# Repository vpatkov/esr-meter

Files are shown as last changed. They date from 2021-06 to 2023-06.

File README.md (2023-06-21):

# ESR meter

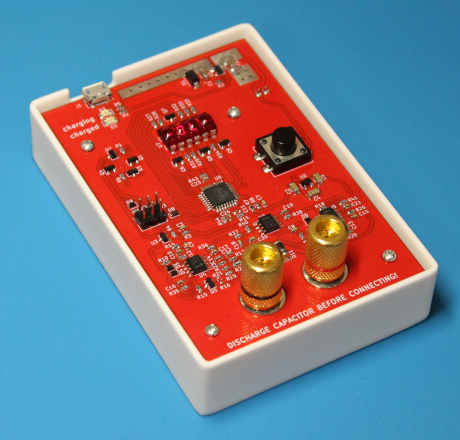
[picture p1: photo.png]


Yet another ESR meter. More precisely, it measures the impedance at 100 kHz in
assumption it's pure resistive. So this meter is not for laboratory
measurements, but for finding bad electrolytic capacitors (a typical fault in
aged electronics).

- The test signal is 100 kHz 50 mVpp 10 Ω sine wave
- Rechargeable from Micro-USB at 300 mA (Li-Po/Li-ion)
- Auto power-off after 3 minutes of inactivity

## Usage

To switch the meter on or off, press the button.

On startup, the meter performs a self-test. Keep the terminals open. During the
test, the meter turns on all the segments on the display, then shows an error
if any. Errors are:

- `E.F.LO`: low fuel (battery voltage < 3.3 V);
- `E.rEF`: something wrong with voltage references or ADC;
- `E.Prb`: something wrong with the test signal (or the terminals aren't open).

When the test is passed, the meter shows the current battery level in percents
as `F <level>`.

During normal operation the meter continuously shows the measured ESR in Ω,
or `-OL-` if it's more than 99.99 Ω.

To compensate test leads (set zero), short the leads and long press the button.
You can't compensate more than 2 Ω — find a better leads or connect capacitors
directly to the binding post. Note that inductance of wires matters at 100 kHz.
If the meter refuse to compensate, it shows `SHIt` (stands for "your leads are
shit").

## License

Unless otherwise noted, this work is licensed under Creative Commons Zero 1.0.



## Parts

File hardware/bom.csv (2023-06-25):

# | Reference | Qty | Value | Footprint | DNP | Note
1 | C1, C6 | 2 | 4.7μ | Capacitor_SMD:C_1206_3216Metric
2 | C2, C4, C5 | 3 | 1μ | Capacitor_SMD:C_1206_3216Metric
3 | C3, C8, C16, C17, C18, C19, C20, C21, C22, C23, C24 | 11 | 100n | Capacitor_SMD:C_0603_1608Metric
4 | C7, C9, C10, C15 | 4 | 10n | Capacitor_SMD:C_0603_1608Metric
5 | C11 | 1 |  | Capacitor_SMD:C_0603_1608Metric | DNP
6 | C12, C14 | 2 | 1n | Capacitor_SMD:C_0603_1608Metric |  | NP0
7 | C13 | 1 | 1n | Capacitor_SMD:C_0603_1608Metric
8 | D1 | 1 | SMAJ5.0A | Diode_SMD:D_SMA
9 | D2 | 1 | RED | LED_SMD:LED_1206_3216Metric
10 | D3 | 1 | GREEN | LED_SMD:LED_1206_3216Metric
11 | D4, D5, D6, D7, D9 | 5 | BAS316 | Diode_SMD:D_SOD-323
12 | D8 | 1 | BAT54J | Diode_SMD:D_SOD-323F
13 | D10, D11 | 2 | SM4007 | Diode_SMD:D_MELF
14 | J1 | 1 | USB_B_Micro | Connector_USB:USB_Micro-B_Molex-105017-0001
15 | J2 | 1 | JST-XH | Connector_JST:JST_XH_S2B-XH-A-1_1x02_P2.50mm_Horizontal
16 | J3 | 1 | Pin Header Male | Connector_PinHeader_2.54mm:PinHeader_2x03_P2.54mm_Vertical
17 | J4 | 1 | Binding Post | esr-meter:BindingPost
18 | Q1, Q3, Q4, Q6, Q7, Q8, Q9 | 7 | DTC114E | Package_TO_SOT_SMD:SOT-23
19 | Q2 | 1 | IRLML6402 | Package_TO_SOT_SMD:SOT-23
20 | Q5 | 1 | MMBFJ113 | Package_TO_SOT_SMD:SOT-23
21 | R1, R6, R22 | 3 | 33k | Resistor_SMD:R_0603_1608Metric
22 | R2 | 1 | 3.3k | Resistor_SMD:R_0603_1608Metric
23 | R3, R4 | 2 | 3k | Resistor_SMD:R_0603_1608Metric
24 | R5, R9, R10, R18 | 4 | 10k | Resistor_SMD:R_0603_1608Metric
25 | R7 | 1 | 31.6k | Resistor_SMD:R_0603_1608Metric |  | 1%
26 | R8 | 1 | 10k | Resistor_SMD:R_0603_1608Metric |  | 1%
27 | R11 | 1 | 100 | Resistor_SMD:R_0603_1608Metric
28 | R12, R13 | 2 | 100k | Resistor_SMD:R_0603_1608Metric
29 | R14, R15, R26 | 3 | 1k | Resistor_SMD:R_0603_1608Metric
30 | R16 | 1 |  | Resistor_SMD:R_0603_1608Metric | DNP
31 | R17, R23 | 2 | 1.58k | Resistor_SMD:R_0603_1608Metric |  | 1%
32 | R19, R37 | 2 | 1k | Resistor_SMD:R_0603_1608Metric |  | 1%
33 | R20 | 1 | 3.3M | Resistor_SMD:R_0603_1608Metric
34 | R21 | 1 | 2.2k | Resistor_SMD:R_0603_1608Metric |  | 1%
35 | R24 | 1 | 499 | Resistor_SMD:R_0805_2012Metric |  | 1%
36 | R25 | 1 | 10 | Resistor_SMD:R_0805_2012Metric |  | 1%
37 | R27, R28, R29, R30, R31, R32, R33, R34 | 8 | 2.4k | Resistor_SMD:R_0603_1608Metric
38 | R35, R36, R38, R39, R41, R42, R43, R44 | 8 | 10 | Resistor_SMD:R_0603_1608Metric
39 | R40 | 1 | 45.3k | Resistor_SMD:R_0603_1608Metric |  | 1%
40 | SW1 | 1 | SW_Push | Button_Switch_THT:SW_PUSH-12mm_Wuerth-430476085716
41 | U1 | 1 | MCP73831 | Package_TO_SOT_SMD:SOT-23-5
42 | U2 | 1 | TPS60403 | Package_TO_SOT_SMD:SOT-23-5
43 | U3 | 1 | TLV431 | Package_TO_SOT_SMD:SOT-23
44 | U4, U5, U8 | 3 | OPA1678 | Package_SO:SO-8_3.9x4.9mm_P1.27mm
45 | U6 | 1 | ATmega88PA-AU | Package_QFP:TQFP-32_7x7mm_P0.8mm
46 | U7 | 1 | QDSP-6064 | Package_DIP:DIP-12_W7.62mm

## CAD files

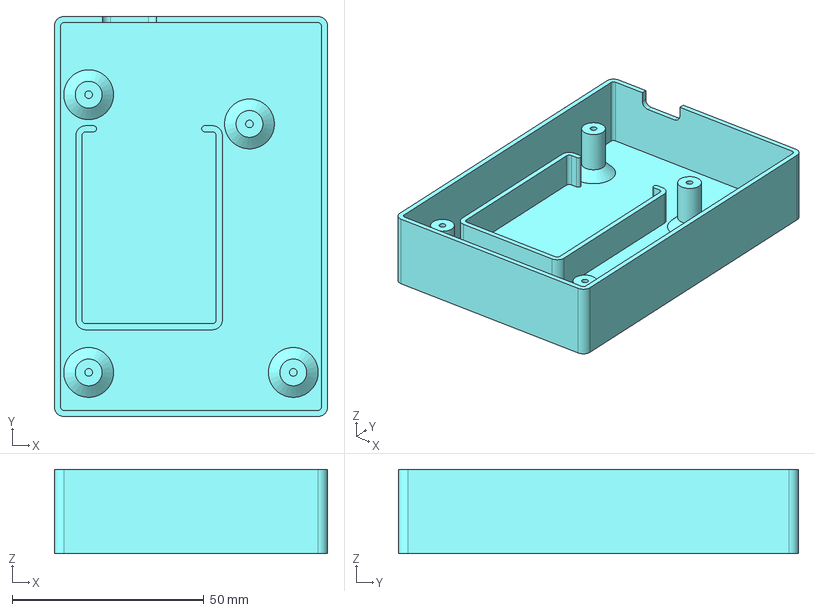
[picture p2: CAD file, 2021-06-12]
case/case.FCStd
71.2 x 104.3 x 22.0 mm

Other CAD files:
case/case.stl

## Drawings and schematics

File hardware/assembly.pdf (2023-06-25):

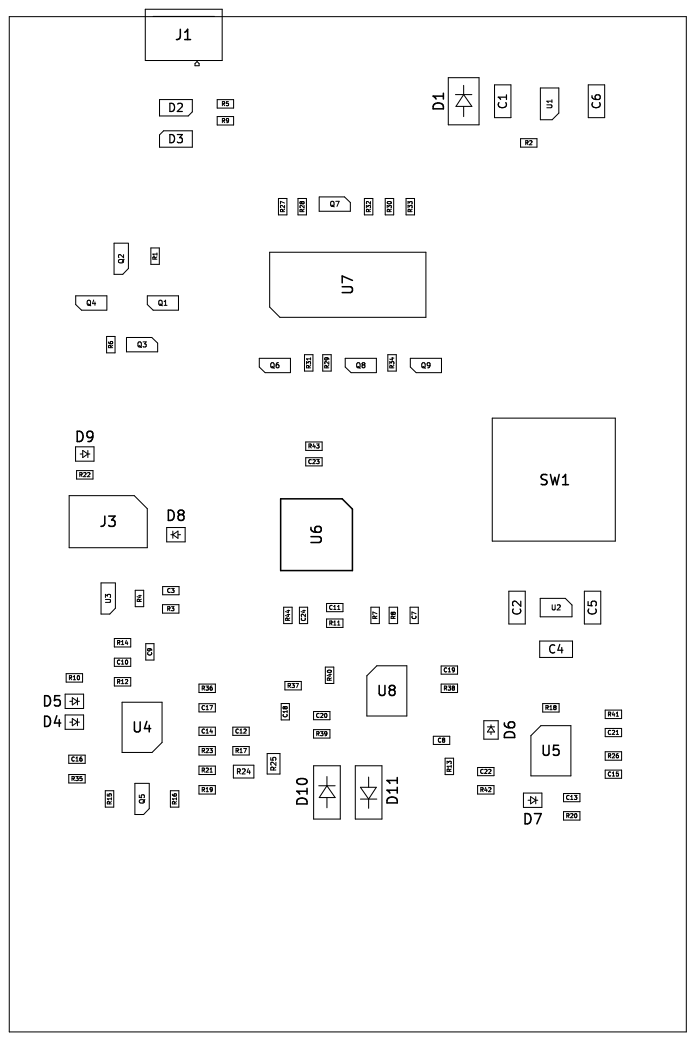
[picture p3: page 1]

Id: 1/1 Title: ESR meter File: esr-meter.kicad_pcb Sheet:

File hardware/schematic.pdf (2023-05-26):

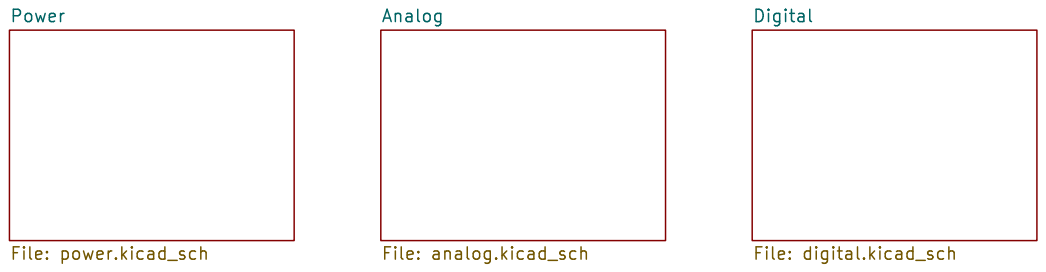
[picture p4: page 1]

Analog File: analog.kicad_sch Power File: power.kicad_sch

Id: 1/4 Title: ESR meter File: esr-meter.kicad_sch Sheet: /

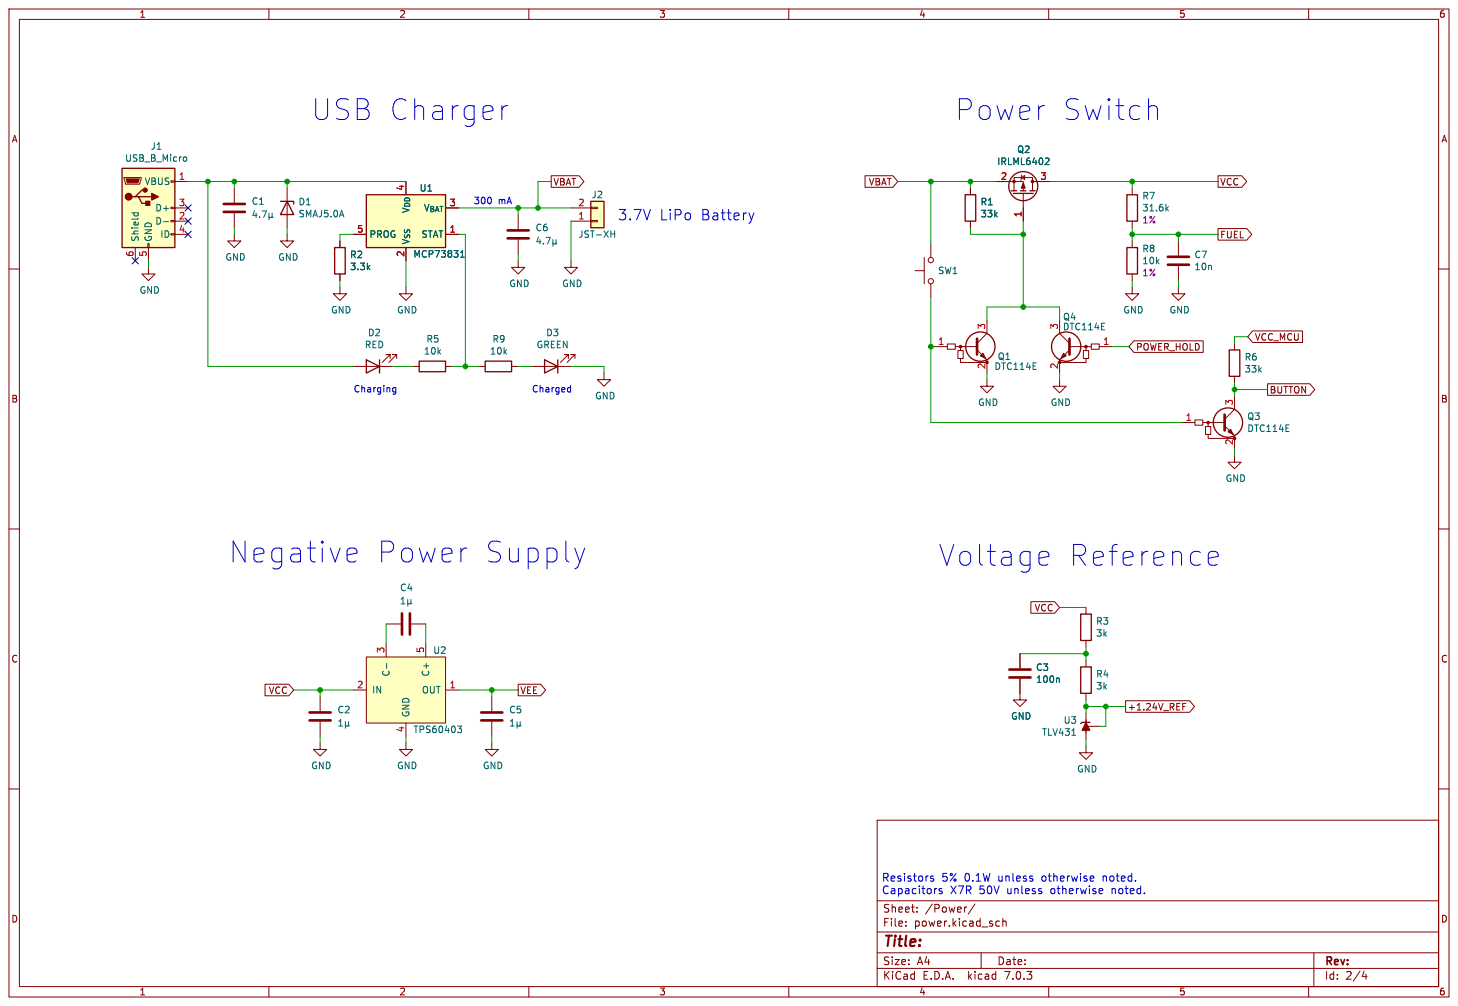
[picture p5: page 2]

Id: 2/4 Title: File: power.kicad_sch Sheet: /Power/

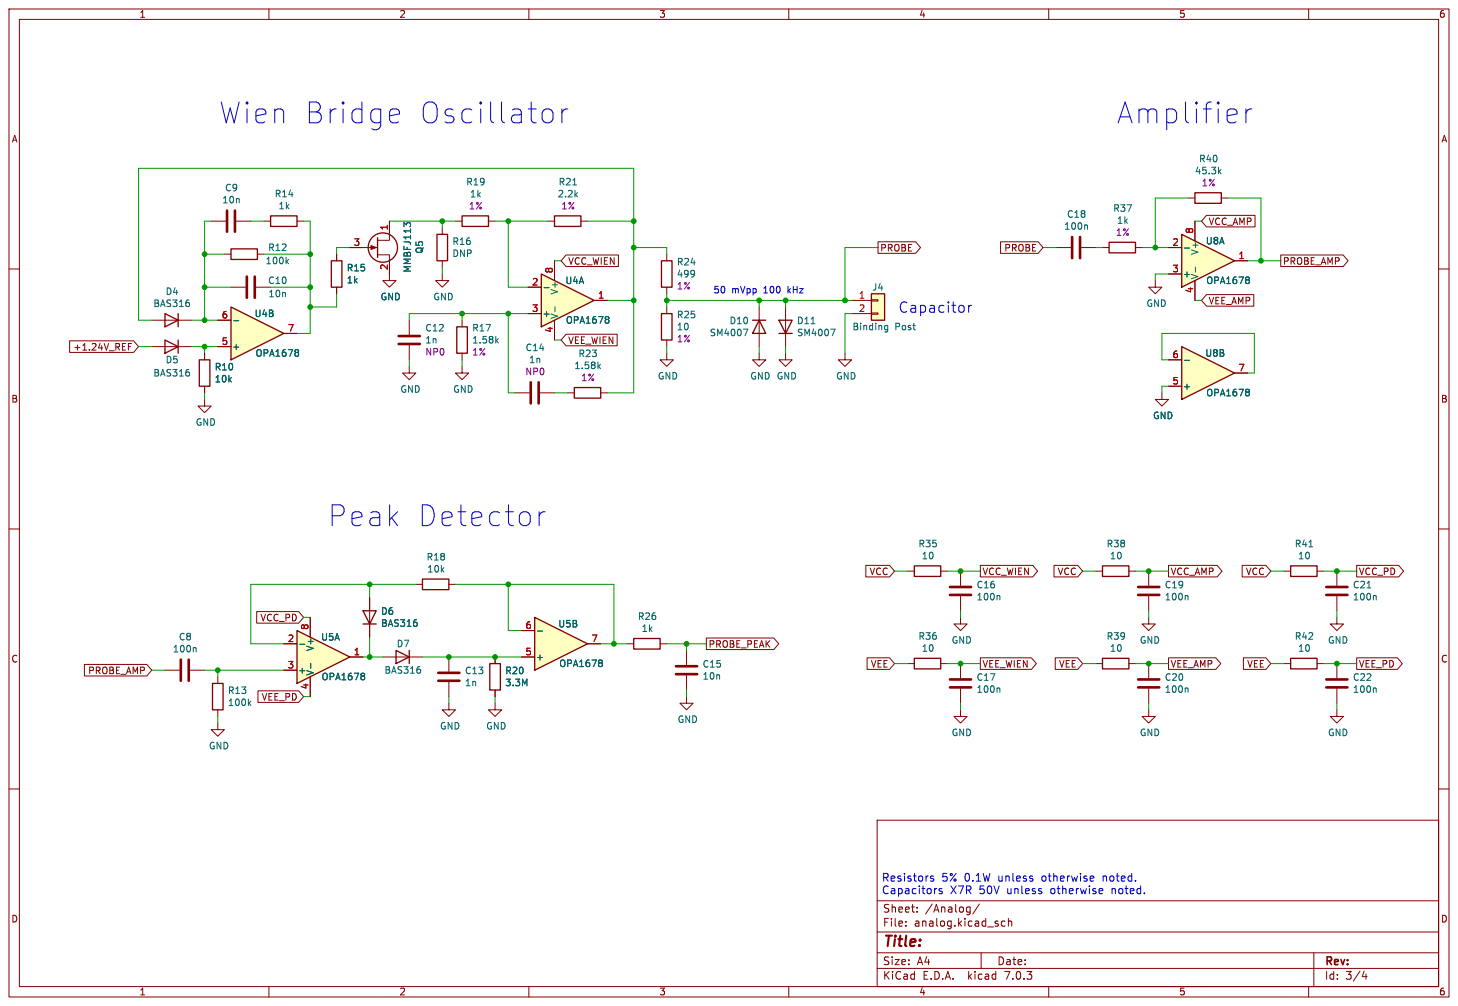
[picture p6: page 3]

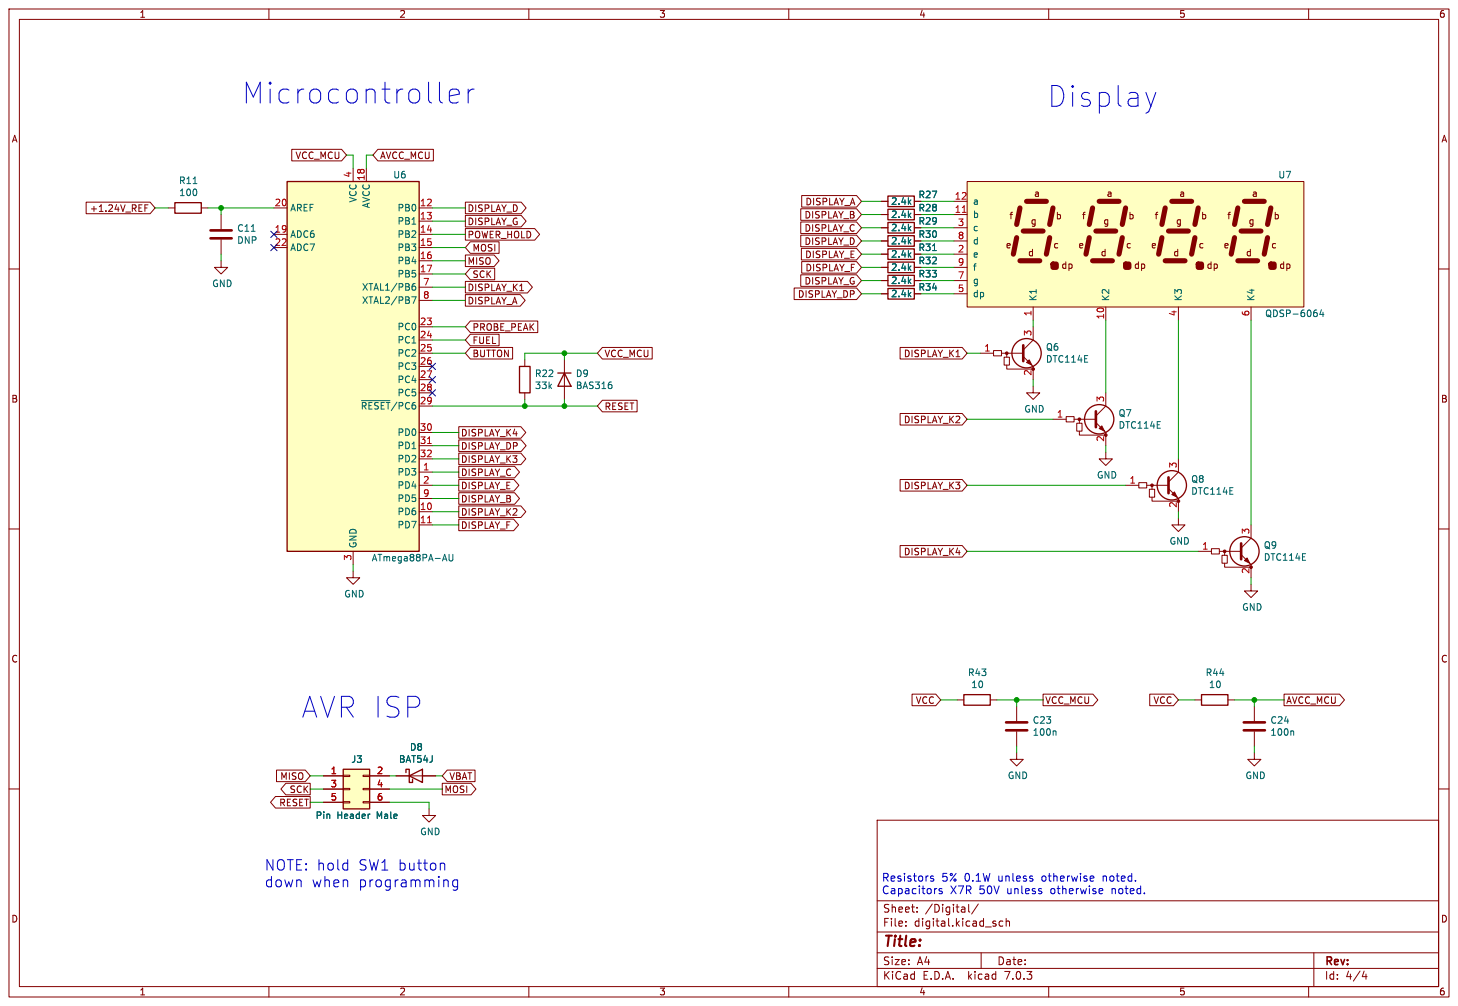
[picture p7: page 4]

Id: 4/4 Title: File: digital.kicad_sch Sheet: /Digital/

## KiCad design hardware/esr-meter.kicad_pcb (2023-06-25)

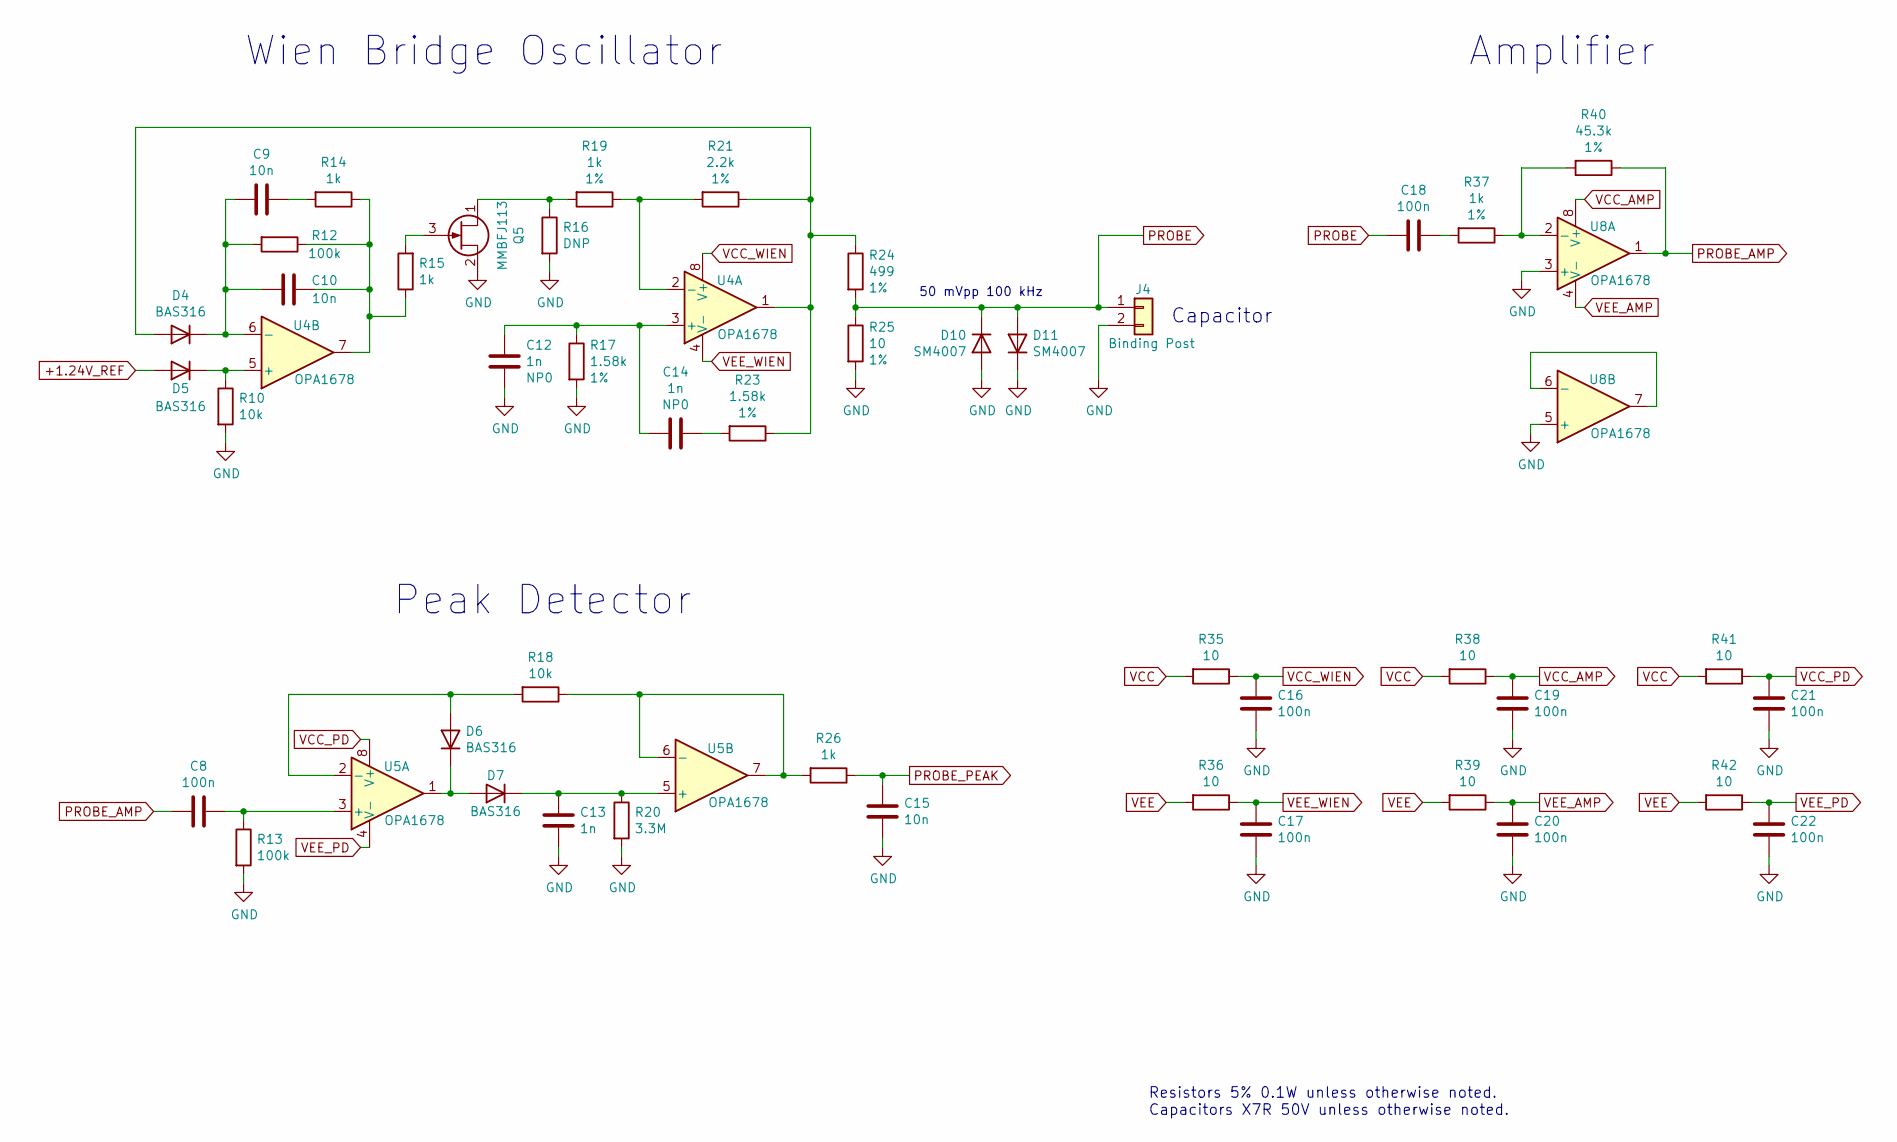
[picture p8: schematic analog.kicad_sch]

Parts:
C8, C16, C17, C18, C19, C20, C21, C22: 100n; C_0603_1608Metric
C9, C10, C15: 10n; C_0603_1608Metric
C12, C13, C14: 1n; C_0603_1608Metric
D4, D5, D6, D7: BAS316; D_SOD-323
D10, D11: SM4007; D_MELF
J4: Binding Post; BindingPost
Q5: MMBFJ113; SOT-23
R10, R18: 10k; R_0603_1608Metric
R12, R13: 100k; R_0603_1608Metric
R14, R15, R19, R26, R37: 1k; R_0603_1608Metric
R16: DNP; R_0603_1608Metric
R17, R23: 1.58k; R_0603_1608Metric
R20: 3.3M; R_0603_1608Metric
R21: 2.2k; R_0603_1608Metric
R24: 499; R_0805_2012Metric
R25: 10; R_0805_2012Metric
R35, R36, R38, R39, R41, R42: 10; R_0603_1608Metric
R40: 45.3k; R_0603_1608Metric
U4, U5, U8: OPA1678; SO-8_3.9x4.9mm_P1.27mm

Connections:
+1.24V_REF: D5.2 (A); also elsewhere on the board
GND: C12.2, C13.2, C15.2, C16.2, C17.2, C19.2, C20.2, C21.2, C22.2, D10.2 (A), D11.1 (K), J4.2, Q5.2 (S), R10.2, R13.2, R16.2, R17.2, R20.2, R25.2, U8.3 (+), U8.5 (+); also elsewhere on the board
unnamed: C9.1, R14.2
unnamed: C10.1, R12.1, R14.1, R15.1, U4.7
unnamed: C14.1, R23.2
unnamed: C18.1, R37.2
unnamed: D4.2 (A), R21.1, R23.1, R24.1, U4.1
unnamed: C9.2, C10.2, D4.1 (K), R12.2, U4.6 (-)
unnamed: D5.1 (K), R10.1, U4.5 (+)
unnamed: D6.2 (A), R18.2, U5.2 (-)
unnamed: D6.1 (K), D7.2 (A), U5.1
unnamed: C13.1, D7.1 (K), R20.1, U5.5 (+)
unnamed: Q5.1 (D), R16.1, R19.2
unnamed: Q5.3 (G), R15.2
unnamed: C12.1, C14.2, R17.1, U4.3 (+)
unnamed: R19.1, R21.2, U4.2 (-)
unnamed: C8.1, R13.1, U5.3 (+)
unnamed: R18.1, R26.2, U5.6 (-), U5.7
unnamed: R37.1, R40.2, U8.2 (-)
unnamed: U8.6 (-), U8.7
PROBE: C18.2, D10.1 (K), D11.2 (A), J4.1, R24.2, R25.1
PROBE_AMP: C8.2, R40.1, U8.1
PROBE_PEAK: C15.1, R26.1; also elsewhere on the board
VCC: R35.2, R38.2, R41.2; also elsewhere on the board
VCC_AMP: C19.1, R38.1, U8.8 (V+)
VCC_PD: C21.1, R41.1, U5.8 (V+)
VCC_WIEN: C16.1, R35.1, U4.8 (V+)
VEE: R36.2, R39.2, R42.2; also elsewhere on the board
VEE_AMP: C20.1, R39.1, U8.4 (V-)
VEE_PD: C22.1, R42.1, U5.4 (V-)
VEE_WIEN: C17.1, R36.1, U4.4 (V-)

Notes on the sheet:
50 mVpp 100 kHz
Amplifier
Peak Detector
Wien Bridge Oscillator
Resistors 5% 0.1W unless otherwise noted. Capacitors X7R 50V unless otherwise noted.
Capacitor

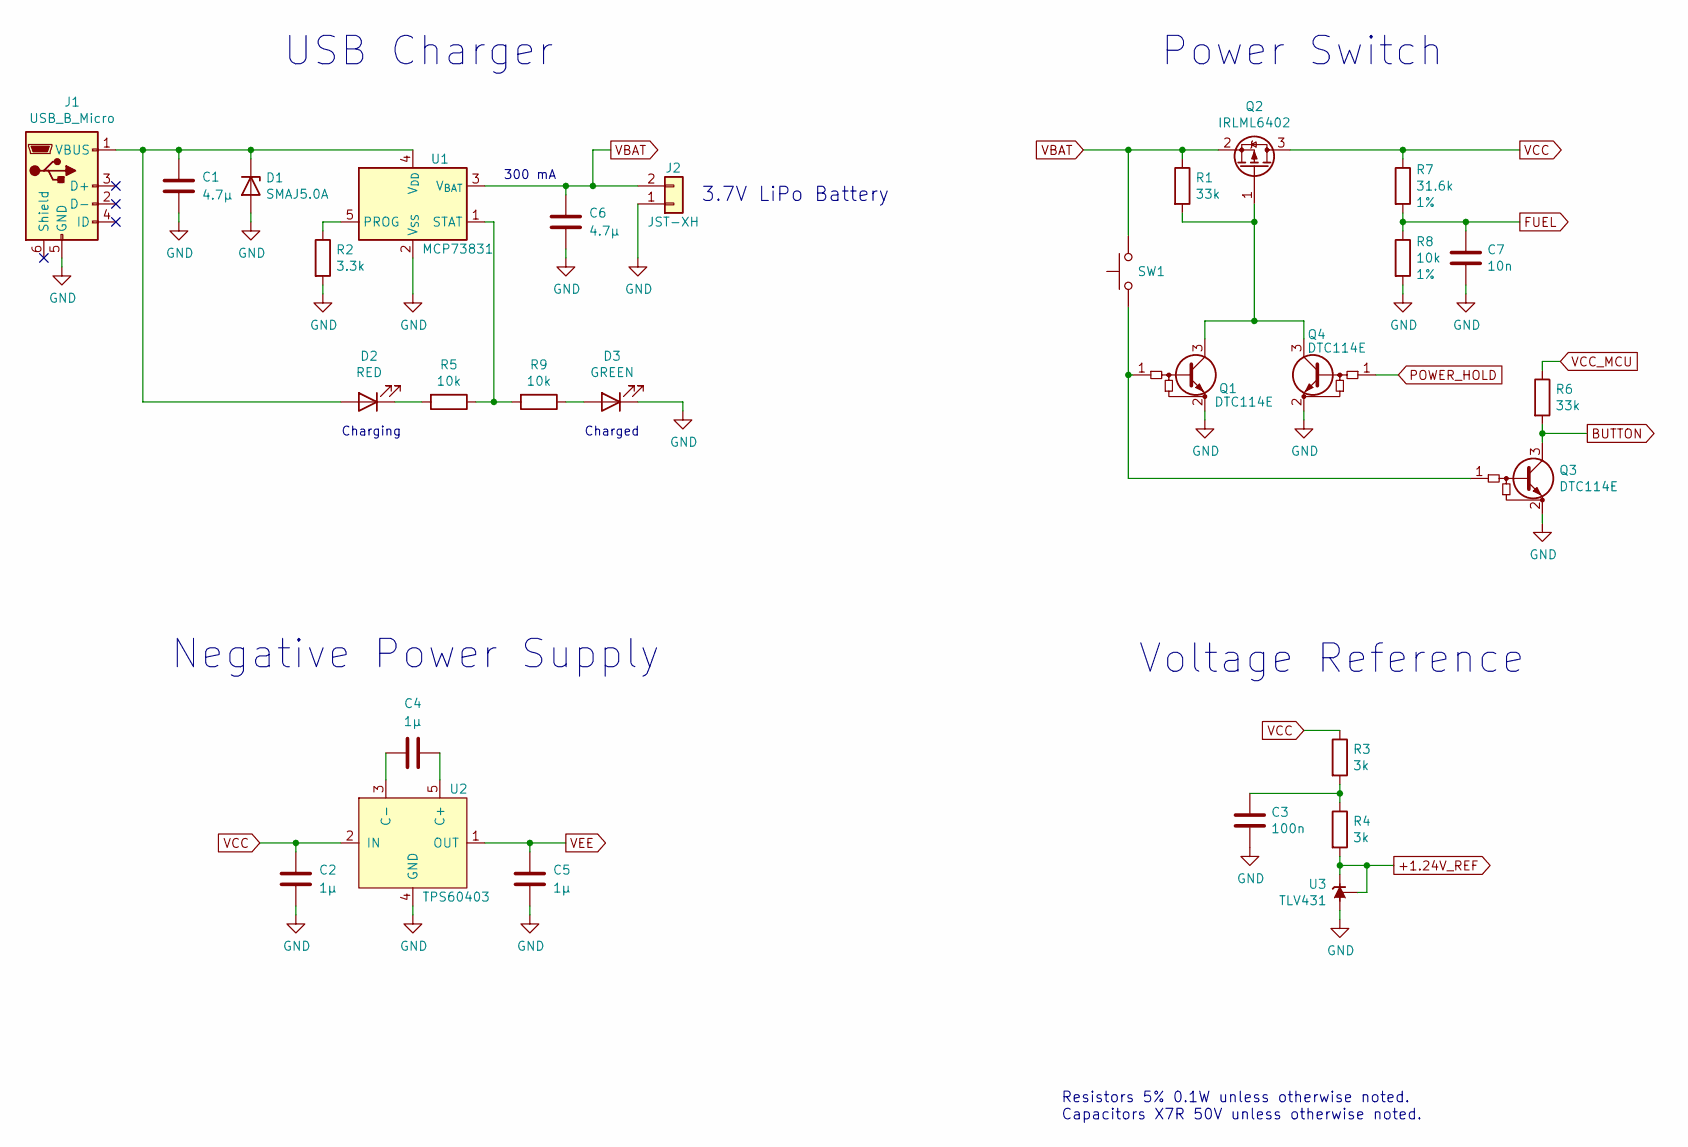
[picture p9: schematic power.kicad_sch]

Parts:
C1, C6: 4.7μ; C_1206_3216Metric
C2, C4, C5: 1μ; C_1206_3216Metric
C3: 100n; C_0603_1608Metric
C7: 10n; C_0603_1608Metric
D1: SMAJ5.0A; D_SMA
D2: RED; LED_1206_3216Metric
D3: GREEN; LED_1206_3216Metric
J1: USB_B_Micro; USB_Micro-B_Molex-105017-0001
J2: JST-XH; JST_XH_S2B-XH-A-1_1x02_P2.50mm_Horizontal
Q1, Q3, Q4: DTC114E; SOT-23
Q2: IRLML6402; SOT-23
R1, R6: 33k; R_0603_1608Metric
R2: 3.3k; R_0603_1608Metric
R3, R4: 3k; R_0603_1608Metric
R5, R8, R9: 10k; R_0603_1608Metric
R7: 31.6k; R_0603_1608Metric
SW1: SW_Push; SW_PUSH-12mm_Wuerth-430476085716
U1: MCP73831; SOT-23-5
U2: TPS60403; SOT-23-5
U3: TLV431; SOT-23

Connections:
+1.24V_REF: R4.2, U3.1 (K), U3.2 (REF); also elsewhere on the board
BUTTON: Q3.3 (C), R6.2; also elsewhere on the board
FUEL: C7.1, R7.2, R8.1; also elsewhere on the board
GND: C1.2, C2.2, C3.2, C5.2, C6.2, C7.2, D1.2 (A), D3.1 (K), J1.5 (GND), J2.1, Q1.2 (E), Q3.2 (E), Q4.2 (E), R2.2, R8.2, U1.2 (V_{SS}), U2.4 (GND), U3.3 (A); also elsewhere on the board
unnamed: C3.1, R3.2, R4.1
unnamed: C1.1, D1.1 (K), D2.2 (A), J1.1 (VBUS), U1.4 (V_{DD})
unnamed: D2.1 (K), R5.2
unnamed: D3.2 (A), R9.1
unnamed: Q1.1 (B), Q3.1 (B), SW1.1
unnamed: Q1.3 (C), Q2.1 (G), Q4.3 (C), R1.2
unnamed: R2.1, U1.5 (PROG)
unnamed: R5.1, R9.2, U1.1 (STAT)
unnamed: C4.1, U2.5 (C+)
unnamed: C4.2, U2.3 (C-)
POWER_HOLD: Q4.1 (B); also elsewhere on the board
VBAT: C6.1, J2.2, Q2.2 (S), R1.1, SW1.2, U1.3 (V_{BAT}); also elsewhere on the board
VCC: C2.1, Q2.3 (D), R3.1, R7.1, U2.2 (IN); also elsewhere on the board
VCC_MCU: R6.1; also elsewhere on the board
VEE: C5.1, U2.1 (OUT); also elsewhere on the board

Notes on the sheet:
USB Charger
Charging
3.7V LiPo Battery
Resistors 5% 0.1W unless otherwise noted. Capacitors X7R 50V unless otherwise noted.
Voltage Reference
Power Switch
300 mA
Charged
Negative Power Supply

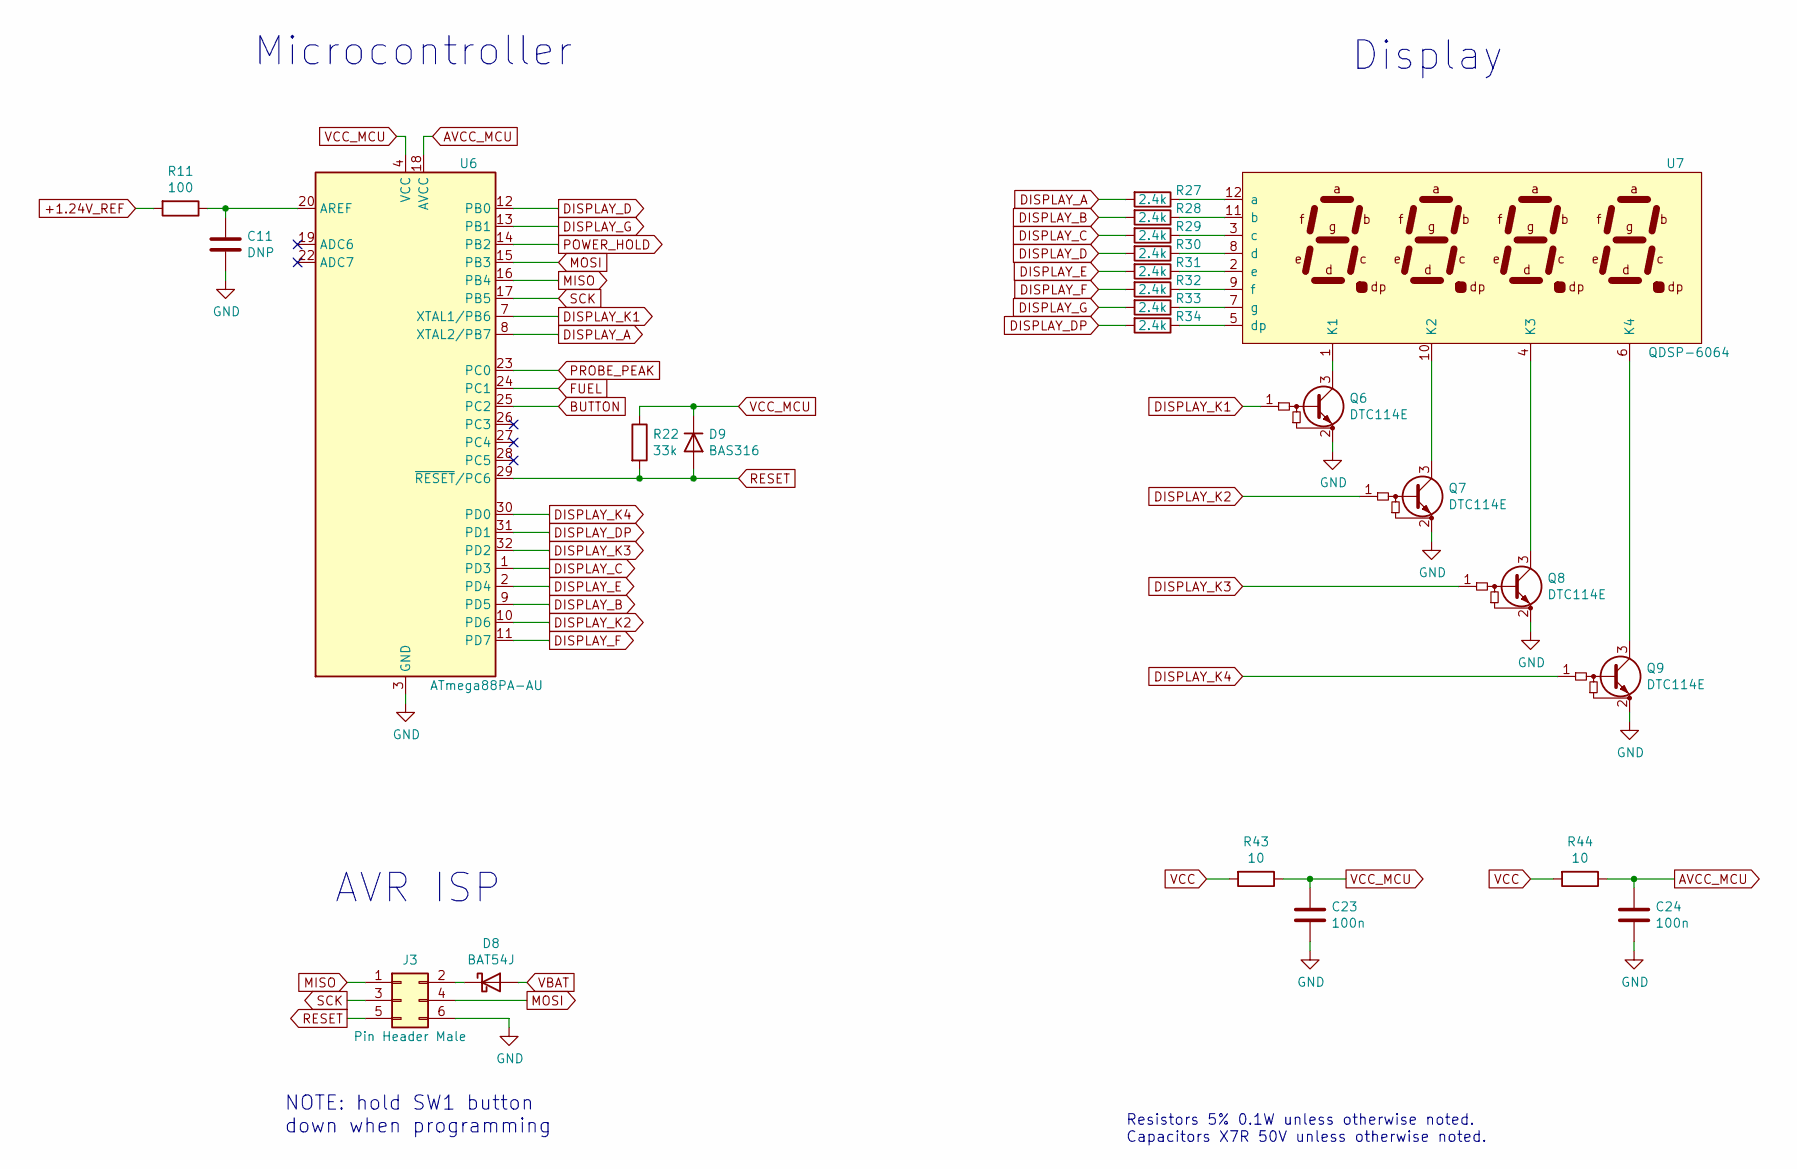
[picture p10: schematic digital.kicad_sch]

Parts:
C11: DNP; C_0603_1608Metric
C23, C24: 100n; C_0603_1608Metric
D8: BAT54J; D_SOD-323F
D9: BAS316; D_SOD-323
J3: Pin Header Male; PinHeader_2x03_P2.54mm_Vertical
Q6, Q7, Q8, Q9: DTC114E; SOT-23
R11: 100; R_0603_1608Metric
R22: 33k; R_0603_1608Metric
R27, R28, R29, R30, R31, R32, R33, R34: 2.4k; R_0603_1608Metric
R43, R44: 10; R_0603_1608Metric
U6: ATmega88PA-AU; TQFP-32_7x7mm_P0.8mm
U7: QDSP-6064; DIP-12_W7.62mm

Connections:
+1.24V_REF: R11.2; also elsewhere on the board
AVCC_MCU: C24.1, R44.1, U6.18 (AVCC)
BUTTON: U6.25 (PC2); also elsewhere on the board
DISPLAY_A: R27.2, U6.8 (XTAL2/PB7)
DISPLAY_B: R28.2, U6.9 (PD5)
DISPLAY_C: R29.2, U6.1 (PD3)
DISPLAY_D: R30.2, U6.12 (PB0)
DISPLAY_DP: R34.2, U6.31 (PD1)
DISPLAY_E: R31.2, U6.2 (PD4)
DISPLAY_F: R32.2, U6.11 (PD7)
DISPLAY_G: R33.2, U6.13 (PB1)
DISPLAY_K1: Q6.1 (B), U6.7 (XTAL1/PB6)
DISPLAY_K2: Q7.1 (B), U6.10 (PD6)
DISPLAY_K3: Q8.1 (B), U6.32 (PD2)
DISPLAY_K4: Q9.1 (B), U6.30 (PD0)
FUEL: U6.24 (PC1); also elsewhere on the board
GND: C11.2, C23.2, C24.2, J3.6, Q6.2 (E), Q7.2 (E), Q8.2 (E), Q9.2 (E), U6.3 (GND), U6.5 (GND), U6.21 (GND); also elsewhere on the board
MISO: J3.1, U6.16 (PB4)
MOSI: J3.4, U6.15 (PB3)
unnamed: D8.1 (K), J3.2
unnamed: Q6.3 (C), U7.1 (K1)
unnamed: Q7.3 (C), U7.10 (K2)
unnamed: Q8.3 (C), U7.4 (K3)
unnamed: Q9.3 (C), U7.6 (K4)
unnamed: C11.1, R11.1, U6.20 (AREF)
unnamed: R27.1, U7.12 (a)
unnamed: R28.1, U7.11 (b)
unnamed: R29.1, U7.3 (c)
unnamed: R30.1, U7.8 (d)
unnamed: R34.1, U7.5 (dp)
unnamed: R31.1, U7.2 (e)
unnamed: R32.1, U7.9 (f)
unnamed: R33.1, U7.7 (g)
POWER_HOLD: U6.14 (PB2); also elsewhere on the board
PROBE_PEAK: U6.23 (PC0); also elsewhere on the board
RESET: D9.2 (A), J3.5, R22.2, U6.29 (~RESET/PC6)
SCK: J3.3, U6.17 (PB5)
VBAT: D8.2 (A); also elsewhere on the board
VCC: R43.2, R44.2; also elsewhere on the board
VCC_MCU: C23.1, D9.1 (K), R22.1, R43.1, U6.4 (VCC), U6.6 (VCC); also elsewhere on the board

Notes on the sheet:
Display
Resistors 5% 0.1W unless otherwise noted. Capacitors X7R 50V unless otherwise noted.
Microcontroller
NOTE: hold SW1 button down when programming
AVR ISP

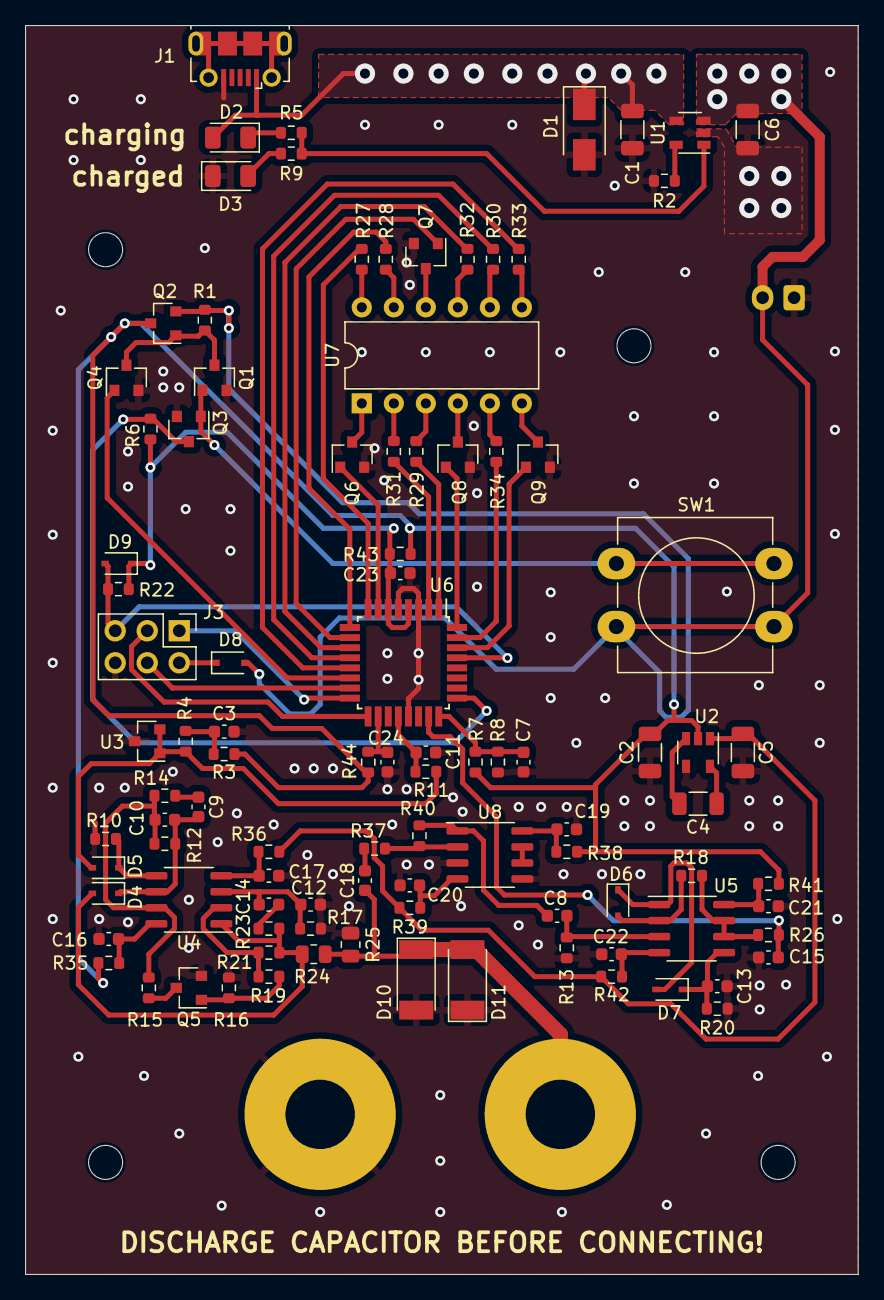
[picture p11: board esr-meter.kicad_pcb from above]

Board: 2 copper layers, 66.0 x 99.1 mm, 101 parts (1 on the bottom side), 77 nets.

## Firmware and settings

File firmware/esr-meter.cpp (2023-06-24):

/* Main program */

#include <stdint.h>
#include <avr/io.h>
#include <avr/pgmspace.h>
#include "common.hpp"
#include "delay.hpp"
#include "volatile.hpp"
#include "gpio.hpp"
#include "bubble.hpp"

/* Peripherals are configured for 8 MHz system clock */
static_assert(F_CPU == 8e6, "");

constexpr Gpio::Pin power_hold = Gpio::B2;
constexpr Gpio::Pin button = Gpio::C2;

constexpr Gpio::Pin unused_pins[] = {
	Gpio::C3,
	Gpio::C4,
	Gpio::C5,
};

constexpr uint8_t probe_adc_channel = 0;
constexpr uint8_t fuel_adc_channel = 1;
constexpr uint8_t iref_adc_channel = 14;

struct Flags {
	bool button_pressed: 1;
	bool button_pressed_long: 1;
	bool probe_updated: 1;
	bool probe_adc_enable: 1;
};

static Bubble display;
static Flags flags;
static uint16_t probe;
static uint16_t probe_open;
static uint8_t inactivity_timer = 0;  /* seconds */

/* 1024 Hz general-purpose interrupt */
ISR(TIMER1_COMPA_vect)
{
	static uint16_t cycle = 0;

	/* Poll the button (32 Hz) */
	if (cycle % 32 == 0) {
		constexpr uint8_t long_press = 16;  /* 0.5 s */
		static uint8_t cnt = 0;
		static bool prev = 1;
		if (Gpio::read(button) != prev) {
			if (prev == 0 && cnt < long_press)
				flags.button_pressed = 1;
			prev = !prev;
			cnt = 0;
		}
		else if (prev == 0) {
			if (cnt <= long_press)
				cnt++;
			if (cnt == long_press)
				flags.button_pressed_long = 1;
		}
	}

	/* Measure the probe voltage  */
	if (flags.probe_adc_enable) {
		constexpr uint8_t nr_samples = 64;  /* 16 Hz */
		static uint8_t cnt = 0;
		static uint16_t acc = 0;

		acc += ADC;
		if (++cnt == nr_samples) {
			probe = acc/nr_samples;
			flags.probe_updated = 1;
			acc = 0;
			cnt = 0;
		}

		ADMUX = probe_adc_channel & 15;
		ADCSRA = 1<<ADEN | 1<<ADSC | 1<<ADPS2 | 1<<ADPS1;  /* 125 kHz */
	}

	/* Scan the display (512 Hz) */
	if (cycle % 2 == 0)
		display.scan();

	/* Increase inactivity timer (1 Hz) */
	if (cycle % 1024 == 0)
		inactivity_timer++;

	cycle++;
}

static void power_off()
{
	Gpio::write(power_hold, 0);
	for (;;) {}
}

static uint16_t adc_measure(uint8_t channel)
{
	constexpr uint8_t nr_samples = 64;

	/* Temporarily disable probe measurements in background */
	bool probe_adc_enable = flags.probe_adc_enable;
	flags.probe_adc_enable = 0;

	uint16_t acc = 0;

	/* Averaging */
	for (uint8_t i = 0; i < nr_samples; i++) {
		ADMUX = channel & 15;
		ADCSRA = 1<<ADEN | 1<<ADSC | 1<<ADPS2 | 1<<ADPS1;  /* 125 kHz */
		while (ADCSRA & (1<<ADSC))
			memory_barrier();
		acc += ADC;
	}

	/* Restore the flag */
	flags.probe_adc_enable = probe_adc_enable;

	return acc/nr_samples;
}

static void self_test()
{
	/* Check the display and skip transients after power on */
	display.printf(PSTR("\n8.8.8.8."));
	delay_ms(500);

	/* Check internal (1.1 V) vs external (1.24 V) references */
	constexpr uint16_t iref_min = 1.1 * 1024/1.24 * 0.9;
	constexpr uint16_t iref_max = 1.1 * 1024/1.24 * 1.1;
	uint16_t iref = adc_measure(iref_adc_channel);
	if (iref < iref_min || iref > iref_max) {
		display.printf(PSTR("\nE.rEF"));
		delay_s(1);
		power_off();
	}

	/* Check the battery voltage */
	constexpr uint16_t fuel_min = 3.3/(31.6+10)*10 * 1024/1.24;
	constexpr uint16_t fuel_max = 4.2/(31.6+10)*10 * 1024/1.24;
	uint16_t fuel = adc_measure(fuel_adc_channel);
	if (fuel < fuel_min) {
		display.printf(PSTR("\nE.F.LO"));
		delay_s(1);
		power_off();
	}

	/* Check and save the open probe voltage */
	constexpr uint16_t probe_min = 25e-3 * 45.3 * 1024/1.24 * 0.8;
	constexpr uint16_t probe_max = 1023;
	probe_open = adc_measure(probe_adc_channel);
	if (probe_open < probe_min || probe_open == probe_max) {
		display.printf(PSTR("\nE.Prb"));
		delay_s(1);
		power_off();
	}

	/* Show the battery level in % */
	uint8_t fuel_percents = (fuel - fuel_min) * 100 / (fuel_max - fuel_min);
	display.printf(PSTR("\nF%3u"), fuel_percents);
	delay_ms(500);
}

/* Return ESR in Ω/100 */
static int16_t calc_esr(uint16_t v_loaded, uint16_t v_open, uint16_t r_zero)
{
	constexpr int32_t r_out = 499.0*10.0/(499.0+10.0) * 100;

	int32_t vl = v_loaded, vo = v_open, rz = r_zero;
	int32_t r = (vl >= vo) ? INT32_MAX : r_out * vl / (vo - vl) - rz;

	return min<int32_t>(r, INT16_MAX);
}

int main()
{
	Gpio::write(power_hold, 1);

	for (auto p : unused_pins)
		Gpio::pull_up(p);
	
	/* Disable unused peripherals */
	ACSR = 1<<ACD;
	DIDR0 = 0b111011;
	DIDR1 = 0b11;
	PRR = 1<<PRTWI | 1<<PRTIM2 | 1<<PRTIM0 | 1<<PRSPI | 1<<PRUSART0;

	/* Set up T/C1 for 1024 Hz interrupt */
	TCCR1A = 0;
	TCCR1B = 1<<WGM12 | 1<<CS11 | 1<<CS10;
	OCR1A = 121;
	TIMSK1 = 1<<OCIE1A;

	display.init();
	sei();

	self_test();

	flags = {};
	flags.probe_adc_enable = 1;

	int16_t zero = 0;

	for (;;)
	{
		if (flags.button_pressed || inactivity_timer > 180)
			power_off();

		if (flags.button_pressed_long) {
			int16_t z = calc_esr(atomic_read(probe), probe_open, 0);
			if (z > 200)
				display.printf(PSTR("\nSHIt"));
			else {
				zero = z;
				display.printf(PSTR("\nZErO"));
			}
			inactivity_timer = 0;
			delay_ms(500);
			flags.button_pressed_long = 0;
		}

		if (flags.probe_updated) {
			int16_t r = calc_esr(atomic_read(probe), probe_open, zero);
			if (r > 9999)
				display.printf(PSTR("\n-OL-"));
			else {
				display.printf(PSTR("\n%4.3d\b\b."), r);
				inactivity_timer = 0;
			}
			flags.probe_updated = 0;
		}

		memory_barrier();
	}

	return 0;
}

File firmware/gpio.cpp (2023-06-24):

#include <avr/io.h>
#include "gpio.hpp"
#include "common.hpp"
#include "volatile.hpp"

using namespace Gpio;

static constexpr uint8_t *PORTx(Pin p)
{
	switch (p/8) {
#ifdef PORTA
	case 0: return const_cast<uint8_t*>(&PORTA);
#endif
#ifdef PORTB
	case 1: return const_cast<uint8_t*>(&PORTB);
#endif
#ifdef PORTC
	case 2: return const_cast<uint8_t*>(&PORTC);
#endif
#ifdef PORTD
	case 3: return const_cast<uint8_t*>(&PORTD);
#endif
#ifdef PORTE
	case 4: return const_cast<uint8_t*>(&PORTE);
#endif
#ifdef PORTF
	case 5: return const_cast<uint8_t*>(&PORTF);
#endif
#ifdef PORTG
	case 6: return const_cast<uint8_t*>(&PORTG);
#endif
	default: return nullptr;
	}
}

static constexpr uint8_t *DDRx(uint8_t *portx)
{
	return portx ? (portx - 1) : nullptr;
}

static constexpr uint8_t *PINx(uint8_t *portx)
{
	return portx ? (portx - 2) : nullptr;
}

static constexpr uint8_t mask(Pin p)
{
	return 1 << (p % 8);
}

bool Gpio::read(Pin p)
{
	uint8_t *const portx = PORTx(p);
	memory_barrier();
	const bool v = portx ? *PINx(portx) & mask(p) : 0;
	memory_barrier();
	return v;
}

void Gpio::write(Pin p, bool v)
{
	uint8_t *const portx = PORTx(p);
	if (portx) {
		uint8_t *const ddrx = DDRx(portx);
		const uint8_t m = mask(p);
		memory_barrier();
		set_bits(*portx, m, v);
		memory_barrier();
		set_bits(*ddrx, m, 1);
		memory_barrier();
	}
}

void Gpio::tri(Pin p)
{
	uint8_t *const portx = PORTx(p);
	if (portx) {
		uint8_t *const ddrx = DDRx(portx);
		const uint8_t m = mask(p);
		memory_barrier();
		set_bits(*ddrx, m, 0);
		memory_barrier();
		set_bits(*portx, m, 0);
		memory_barrier();
	}
}

void Gpio::pull_up(Pin p)
{
	uint8_t *const portx = PORTx(p);
	if (portx) {
		uint8_t *const ddrx = DDRx(portx);
		const uint8_t m = mask(p);
		memory_barrier();
		set_bits(*ddrx, m, 0);
		memory_barrier();
		set_bits(*portx, m, 1);
		memory_barrier();
	}
}

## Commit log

2022-02-13 Auto power-off
2023-05-18 Update to KiCad 7 and some minor changes
    [esr-meter.kicad_pcb, esr-meter.kicad_sch, esr-meter.sch]
2023-05-20 Split A2 circuit into A4 pages
    [analog.kicad_sch, digital.kicad_sch, esr-meter.kicad_pcb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]
2023-05-24 Increase ADC resolution
2023-05-26 Change R11 to 100 ohm
    [digital.kicad_sch, esr-meter.kicad_pcb]
2023-06-25 Added BOM and the assembly diagram
    [bom.csv, esr-meter.kicad_pcb]
